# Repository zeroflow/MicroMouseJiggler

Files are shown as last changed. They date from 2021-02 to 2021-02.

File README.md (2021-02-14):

# MicroMouseJiggler
Arduino Pro Micro based mouse jiggler.

It's simple.

It has a button.
You push the button, it starts periodically jiggling your mouse cursor.
You push the button again, it stops jiggling your mouse cursor.

The button glows green when active, and flashes when moving the cursor.
If it's not active, the button glows red, but turns off after a minute.

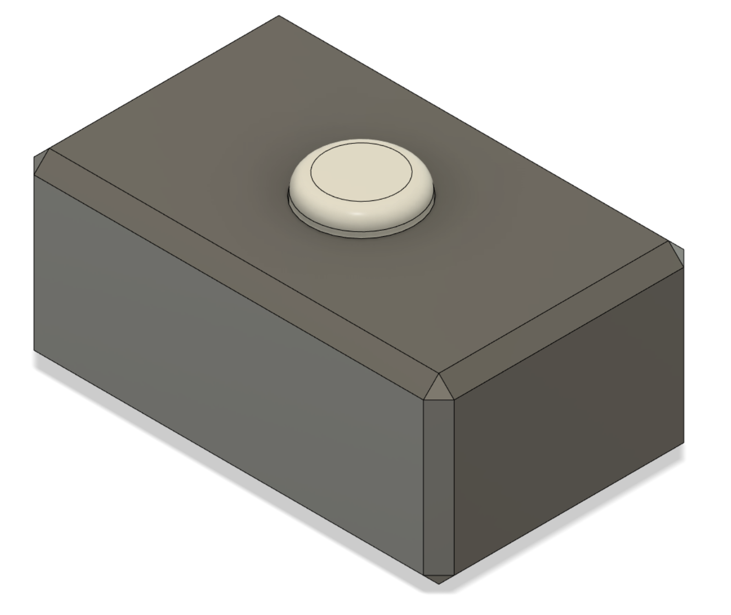
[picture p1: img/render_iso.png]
Rendered image


The PCB is designed to be soldered on top of an Arduino Pro Micro.
To have an easy illuminated button, the lever is illuminated from below by a neopixel LED.

All pieces are designed with 3D printing in mind, but the tolerances are chosen very low for a good fit.

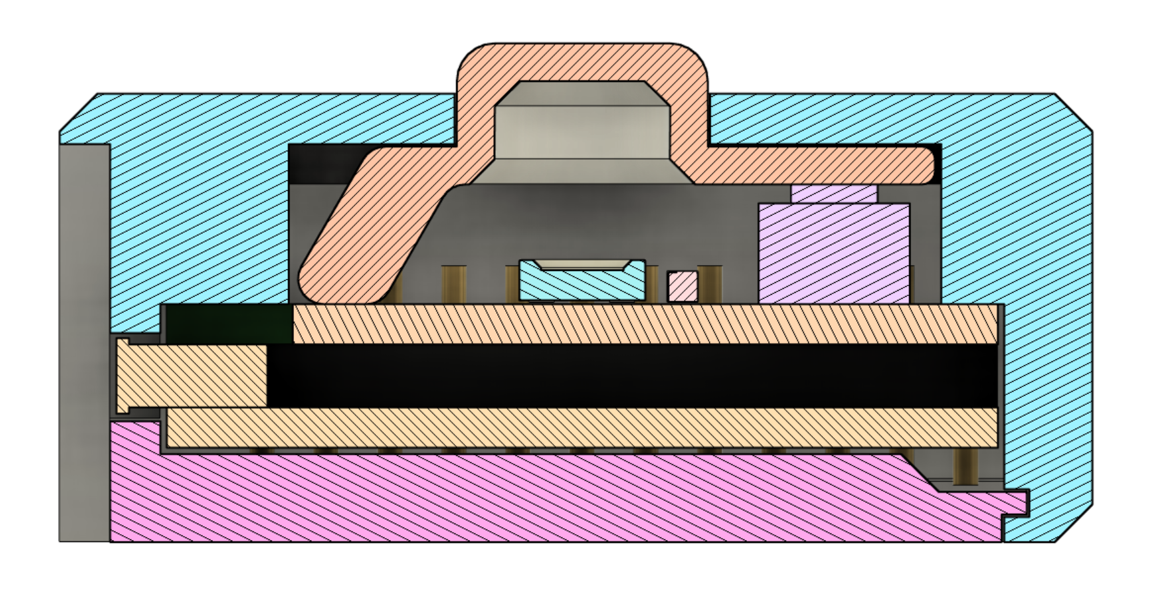
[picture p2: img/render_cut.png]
Cutaway render


CAD source: https://a360.co/3dbTGTp

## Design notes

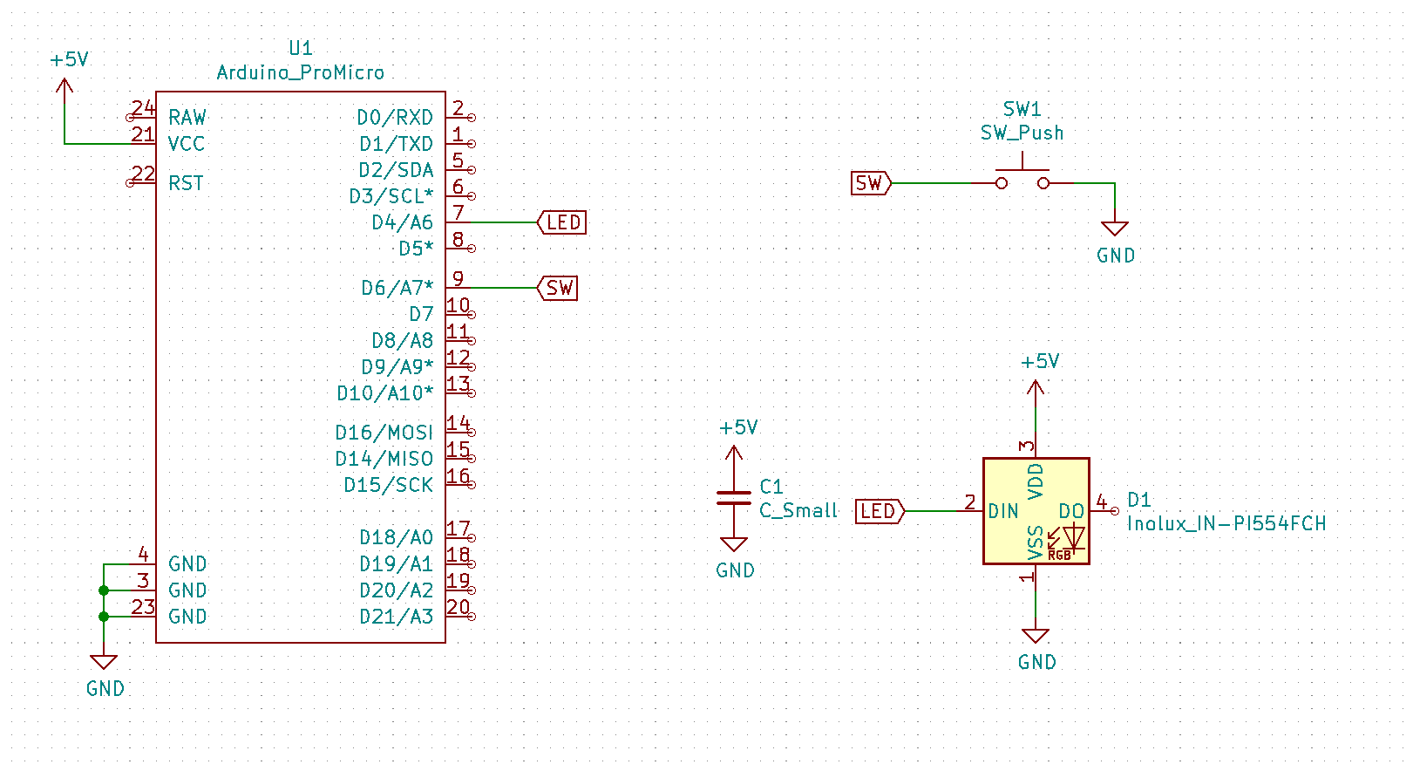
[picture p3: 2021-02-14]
img/schematic.png

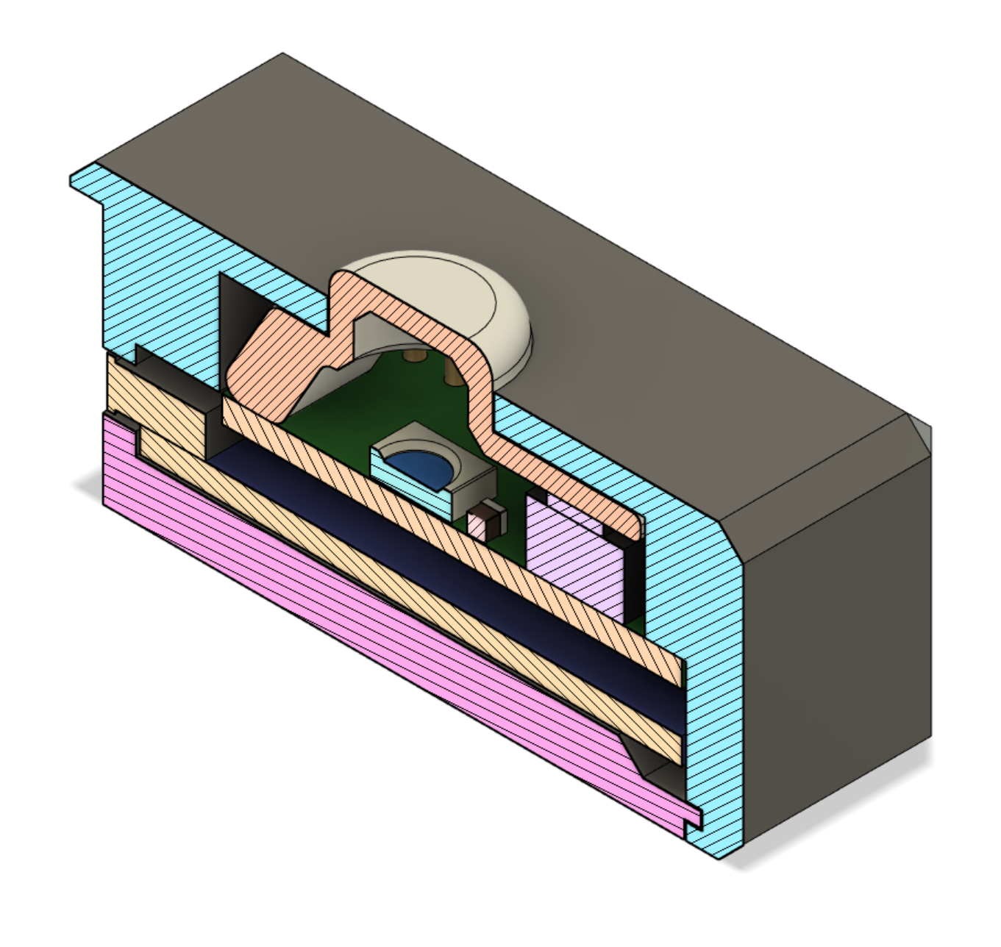
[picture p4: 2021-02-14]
img/render_cut_iso.png

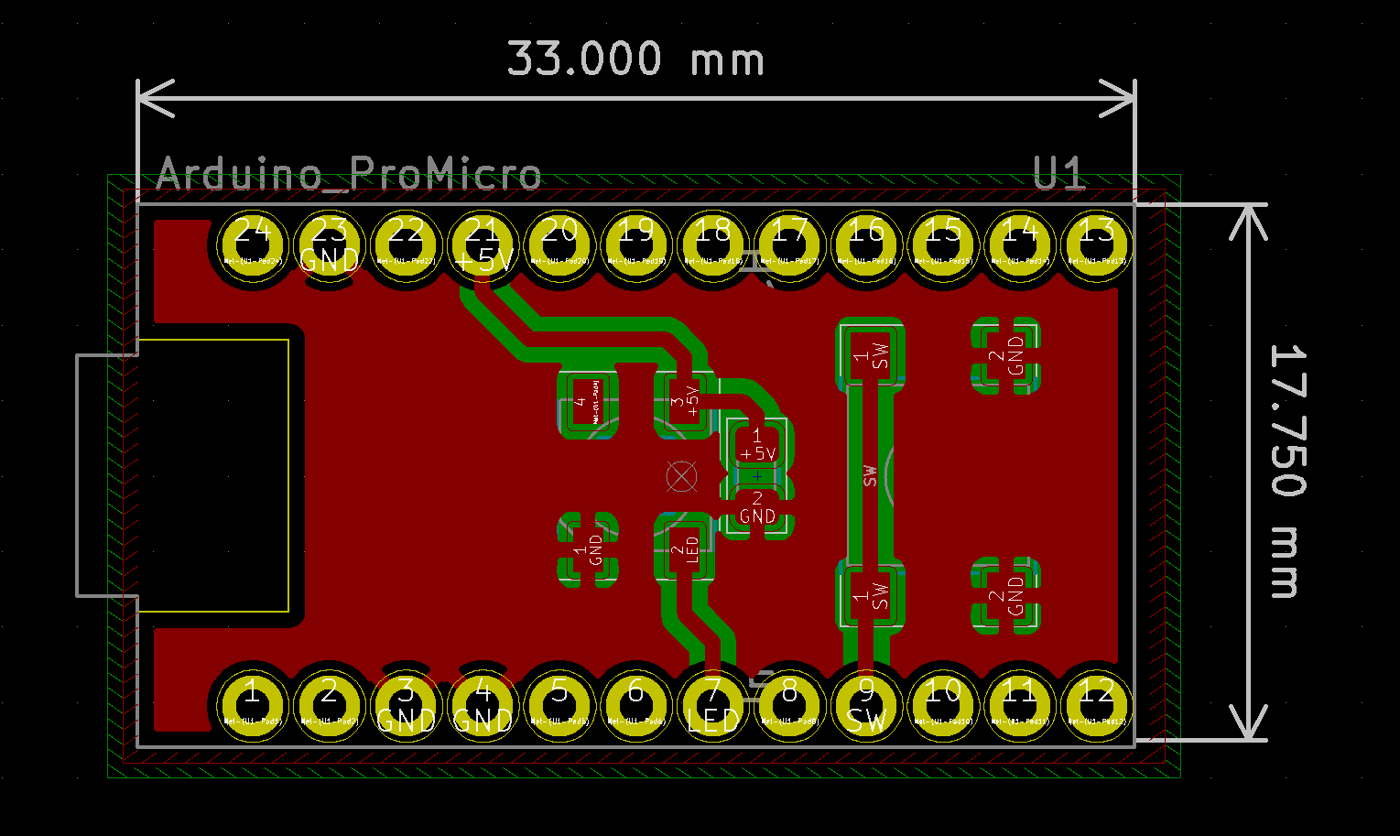
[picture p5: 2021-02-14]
img/pcb.png

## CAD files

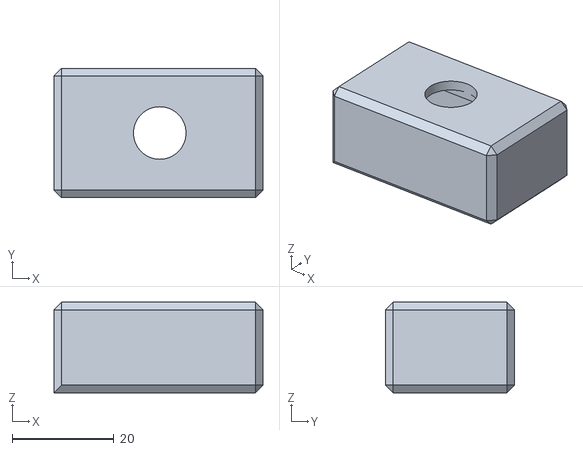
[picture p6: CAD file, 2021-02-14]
Case_Upper_Body.stl
41.0 x 25.4 x 17.8

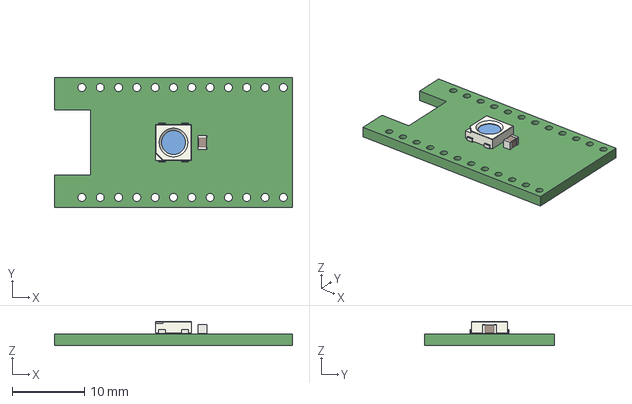
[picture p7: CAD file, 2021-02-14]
PCB/ProMini_MouseJiggler.step
33.0 x 18.0 x 3.35 mm

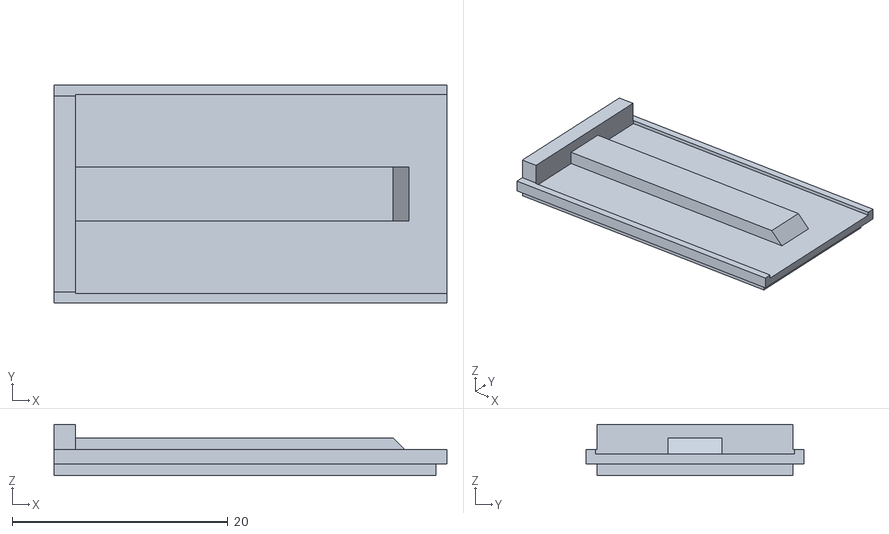
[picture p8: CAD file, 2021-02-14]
Case_Lower_Body.stl
36.4 x 20.2 x 4.75

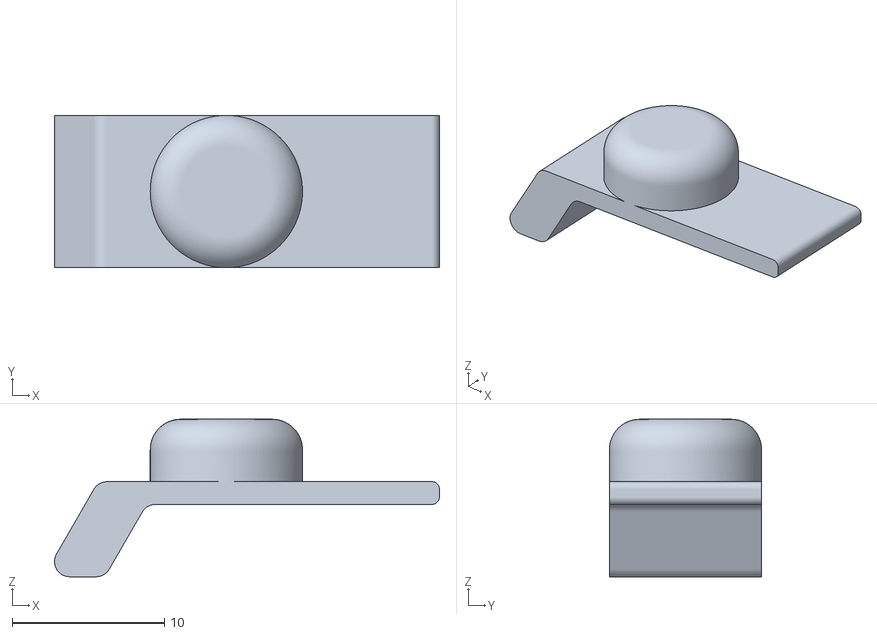
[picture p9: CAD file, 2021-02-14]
Case_Arm.stl
25.3 x 10.0 x 10.3

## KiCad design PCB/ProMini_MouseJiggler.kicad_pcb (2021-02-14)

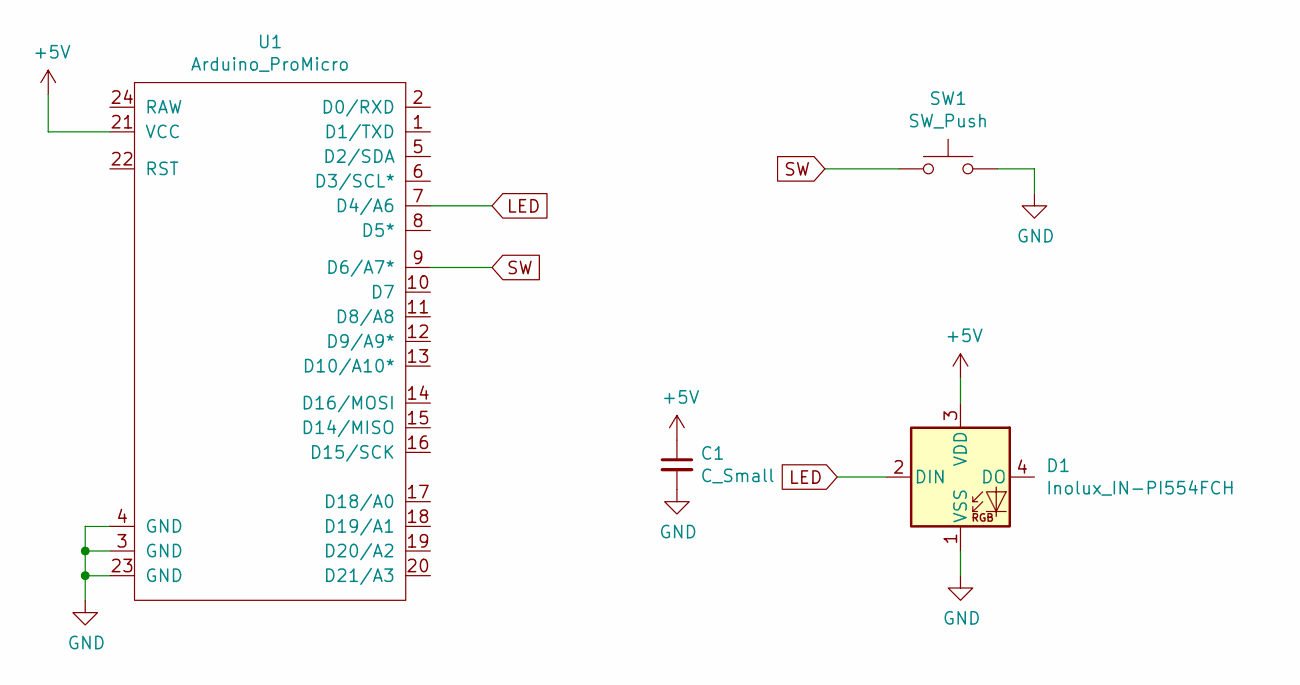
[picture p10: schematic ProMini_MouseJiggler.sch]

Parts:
C1: C_Small; C_0805_2012Metric_Pad1.18x1.45mm_HandSolder
D1: Inolux_IN-PI554FCH; LED_Inolux_IN-PI554FCH_PLCC4_5.0x5.0mm_P3.2mm
SW1: SW_Push; SW_Push_1P1T_NO_6x6mm_H9.5mm
U1: Arduino_ProMicro; Arduino Pro Micro

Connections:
+5V: C1.1, D1.3 (VDD), U1.21 (VCC)
GND: C1.2, D1.1 (VSS), SW1.2, U1.3 (GND), U1.4 (GND), U1.23 (GND)
LED: D1.2 (DIN), U1.7 (D4/A6)
SW: SW1.1, U1.9 (D6/A7*)

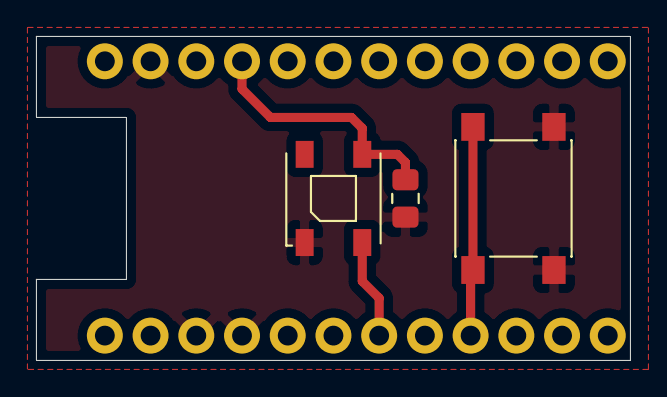
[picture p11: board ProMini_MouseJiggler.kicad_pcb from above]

Board: 2 copper layers, 33.0 x 18.0 mm, 4 parts (0 on the bottom side), 4 nets.

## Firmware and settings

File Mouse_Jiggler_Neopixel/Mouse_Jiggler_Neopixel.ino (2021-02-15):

#include <Mouse.h>
#include <Adafruit_NeoPixel.h>
#include <DebounceEvent.h>
/*
 *  NAME: Arduino Mouse Jiggler
 *  DATE: 2019-09-18
 *  DESC: Arduino based mouse emulator
 *  VERSION: 1.0
 */

/* -------------------------------------- 
 *             C O L O R S
 * -------------------------------------- 
 */

#define COLOR_OFF_IDLE      COLOR(255,0,0)
#define BRIGHTNESS_OFF_IDLE 0

#define COLOR_OFF           COLOR(255,0,0)
#define BRIGHTNESS_OFF      125

#define COLOR_IDLE          COLOR(0,255,0)
#define BRIGHTNESS_IDLE     255

#define COLOR_ACTIVE        COLOR(0,0,255)
#define BRIGHTNESS_ACTIVE   255

/* -------------------------------------- 
 *          B E H A V I O R 
 * -------------------------------------- 
 */

/* Interval of movement in seconds */
#define INTERVAL 10
/* Time after activation for the first jiggle */
#define FIRST_JIGGLE 1
/* Time, after which the system switches from state "OFF" to state "OFF_IDLE" */
#define TIME_IDLE 60

/* Distance (Pixel) to travel */
#define DISTANCE 10
/* Time (ms) between back- and forth movement */
#define TIME 150


/* -------------------------------------- 
 *           H A R D W A R E
 * -------------------------------------- 
 */

/* Pin of Switch */
#define SW_PIN 6
#define CUSTOM_DEBOUNCE_DELAY   50
#define CUSTOM_REPEAT_DELAY     500

/* Neopixel Pin */
#define NP_PIN 4

/* Internals */

//#define DEBUG

#define COLOR(R, G, B) (((uint32_t)R<<16)|((uint32_t)G<<8)|((uint32_t)B))
#define TIME_PASSED(evt, len) ((millis() - evt) > len)

typedef enum {
  OFF_IDLE_st,
  OFF_st,
  IDLE_st,
  ACTIVE_ENTER_st,
  ACTIVE_st,
  ACTIVE_LEAVE_st
} state_te;

state_te state;
unsigned long millis_evt;

Adafruit_NeoPixel pixels(1, NP_PIN, NEO_GRB + NEO_KHZ800);
DebounceEvent * button;

void setup()
{
  /* Set up pins */
  pinMode(SW_PIN, INPUT_PULLUP);
  pinMode(NP_PIN, OUTPUT);

  button = new DebounceEvent(SW_PIN, BUTTON_PUSHBUTTON | BUTTON_DEFAULT_HIGH | BUTTON_SET_PULLUP, CUSTOM_DEBOUNCE_DELAY, CUSTOM_REPEAT_DELAY);

  pixels.begin(); // INITIALIZE NeoPixel strip object (REQUIRED)
  pixels.clear(); // Set all pixel colors to 'off'
  
  /* Enable Mouse */
  Mouse.begin();

  #ifdef DEBUG
  Serial.begin(115200);
  #endif;

  state = OFF_IDLE_st;
}

void LED_off_idle(void)
{
  //pixels.clear(); // Set all pixel colors to 'off'
  pixels.setBrightness(BRIGHTNESS_OFF_IDLE);
  pixels.setPixelColor(0, COLOR_OFF_IDLE);
  pixels.show();   // Send the updated pixel colors to the hardware.
}

void LED_off(void)
{
  //pixels.clear(); // Set all pixel colors to 'off'
  pixels.setBrightness(BRIGHTNESS_OFF);
  pixels.setPixelColor(0, COLOR_OFF);
  pixels.show();   // Send the updated pixel colors to the hardware.
}

void LED_idle(void)
{
  pixels.setBrightness(BRIGHTNESS_IDLE);
  pixels.setPixelColor(0, COLOR_IDLE);
  pixels.show();   // Send the updated pixel colors to the hardware.
}

void LED_active(void)
{
  pixels.setBrightness(BRIGHTNESS_ACTIVE);
  pixels.setPixelColor(0, COLOR_ACTIVE);  
  pixels.show();   // Send the updated pixel colors to the hardware.
}

void loop()
{
  boolean btn_pressed = false;
  
  /* Read button */
  if (unsigned int event = button->loop()) {
      if (event == EVENT_RELEASED) {
        btn_pressed = true;
      }
  }

  switch (state) 
  {
      /* OFF IDLE ---------------------------------------- */
      case OFF_IDLE_st: 
      {
        /* Handle LED in this state */
        LED_off_idle();

        /* Transition OFF -> On */
        if (btn_pressed)
        {
          state = IDLE_st;
          /* Timestamp in the past, to have next event in FIRST_JIGGLE seconds */
          millis_evt = millis() - ((INTERVAL - FIRST_JIGGLE)*1000);
          
          #ifdef DEBUG
          Serial.println("OFF_Idle -> Idle");
          #endif;
        }
        break;
      }
      
      /* OFF --------------------------------------------- */
      case OFF_st:
      {
        /* Handle LED in this state */
        LED_off();

        /* Transition OFF -> On */
        if (btn_pressed)
        {
          state = IDLE_st;
          /* Timestamp in the past, to have next event in FIRST_JIGGLE seconds */
          millis_evt = millis() - ((INTERVAL - FIRST_JIGGLE)*1000);

          #ifdef DEBUG
          Serial.println("OFF -> Idle");
          #endif;
        }

        #ifdef DEBUG
        uint32_t diff = millis()-millis_evt;
        if (diff % 1000 == 0)
        {
          Serial.print("Idle since ");
          Serial.println(diff/1000);
        }
        #endif;

        /* Transition Off -> Off_Idle */
        if (TIME_PASSED(millis_evt, ((uint32_t)TIME_IDLE)*1000))
        {
          state = OFF_IDLE_st;
          
          #ifdef DEBUG
          Serial.println("OFF -> Off_Idle");
          #endif;
        }
        break;
      }
      
      /* IDLE -------------------------------------------- */
      case IDLE_st:
      {
        LED_idle();
        
        /* Transition On -> Off */
        if (btn_pressed)
        {
          state = OFF_st;
          /* Timestamp now, for OFF -> Off_Idle transition */
          millis_evt = millis();

          #ifdef DEBUG
          Serial.println("Idle -> Off");
          #endif;
        }

        /* Transition Off -> Off_Idle */
        if (TIME_PASSED(millis_evt, INTERVAL*1000))
        {
          state = ACTIVE_ENTER_st;
          #ifdef DEBUG
          Serial.println("Idle -> Active_Enter");
          #endif;
        }
        break;
      }
      
      /* ACTIVE --------------------------------------- */
      case ACTIVE_ENTER_st:
      {
        LED_active();

        Mouse.move(DISTANCE, 0, 0);

        state = ACTIVE_st;
        millis_evt = millis();

        #ifdef DEBUG
        Serial.println("Active_Enter -> Active");
        #endif;
          
        break;
      }

      /* ACTIVE --------------------------------------- */
      case ACTIVE_st:
      {
        LED_active();
        
        /* Transition On -> Off */
        if (btn_pressed)
        {
          state = OFF_st;
          /* Timestamp now, for OFF -> Off_Idle transition */
          millis_evt = millis();
        }

        /* Wait specified time to move mouse back */
        if(TIME_PASSED(millis_evt, TIME))
        {
          state = ACTIVE_LEAVE_st;

          #ifdef DEBUG
          Serial.println("Active -> Active_Leave");
          #endif;
        }
        break;
      }

      /* ACTIVE --------------------------------------- */
      case ACTIVE_LEAVE_st:
      {
        LED_active();

        Mouse.move(DISTANCE*-1, 0, 0);

        state = IDLE_st;
        millis_evt = millis();

        #ifdef DEBUG
        Serial.println("Active_Leave -> Idle");
        #endif;
        break;
      }

      /* Default ---------------------------------------- */
      default:
      {
        state = OFF_IDLE_st;
        break;
      }
  }

  delay(1);
}

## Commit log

2021-02-14 Initial Version
    Upload first working version
    [Case_Arm.stl, Case_Lower_Body.stl, Case_Upper_Body.stl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]
2021-02-14 Update README.md
    Replace 2nd picture with cut render
2021-02-15 Update Mouse_Jiggler_Neopixel.ino
    Fix Color macro
    Brighter colors
    [Mouse_Jiggler_Neopixel.ino]
